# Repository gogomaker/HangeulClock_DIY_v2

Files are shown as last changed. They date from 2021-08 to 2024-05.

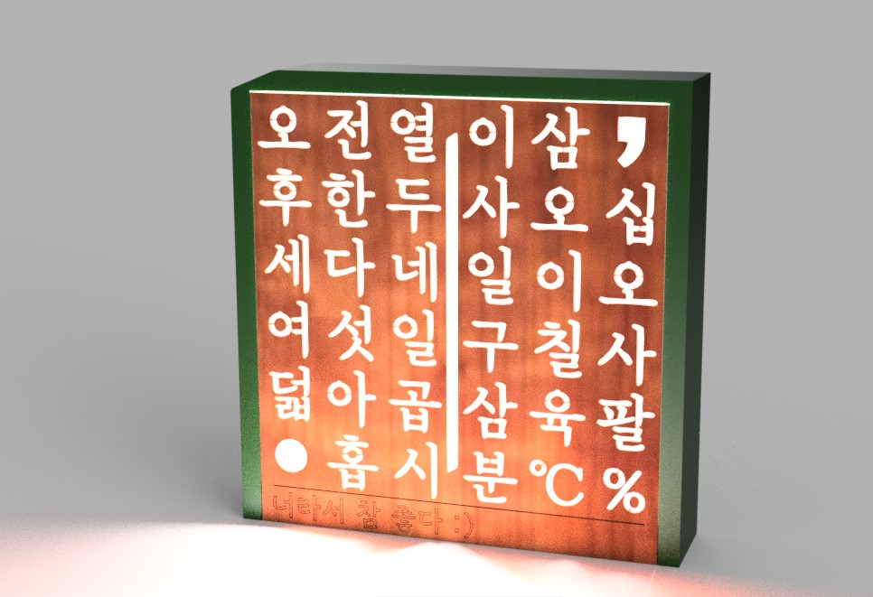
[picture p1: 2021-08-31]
.other_data/렌더링_1.jpg

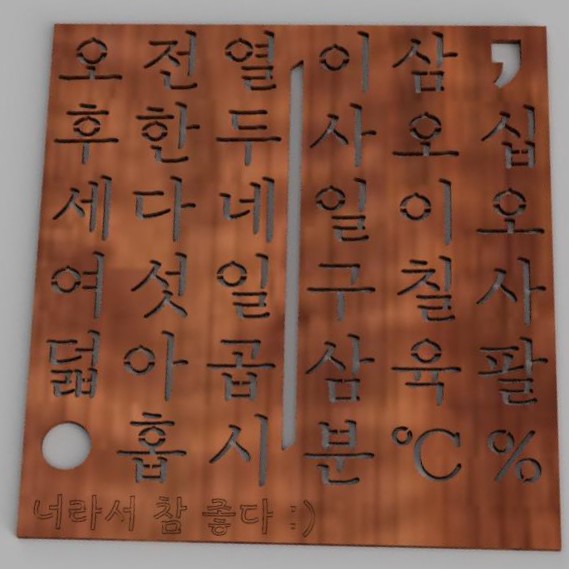
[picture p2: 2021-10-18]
.other_data/한글시계판 렌더링.jpg

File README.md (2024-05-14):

# HangeulClock_DIY_v2
한글시계 v2 - v1을 바탕으로 완전히 새롭게 만드는 v2

## 제작동기: 한글시계 v1을 만들면서 든 한 가지 생각...

'이야 남의 것 배껴서 똑같이 만들었는데 내가 응용해서 만든 것도 하나 있어야지 않겠나...' \
그래서 만들게 된 한글시계 v2 이다. \
-사실 말만 v2이지 상당히 다른 구조를 가지고 있다.

## 이번 프로그래밍에 중요한 사항

특별히 중요한 것은 모든 것을 "함수화"한다는 것이다.

모든 함수는 각자의 기능에 충실하게 작성되어야 하며, 함수 용도 외의 타용도의 코드가 작성되면 안 된다. 반드시 해당 기능만 있어야 한다.

## V2 개선사항(고쳐야 할 점)

PCB에서 flicker 제어선으로 빠지는 곳에 있는 10k옴저항 제거

PCB에 RESET button 추가 및 케이스에 이를 적용

케이스 무게 어떻게든 줄이기(디자인 조정), 전선 꼽히는 부분 조절

외부밝기측정부 재설계(부품이 안 맞으니 조립이 안 됨)

시계의 가장자리 부분으로 빛이 샌다. 이것을 해결할 방법을 찾아야 함.

회로설계에서 버튼핀 재배열 좀 하자(어째서 모드버튼만 2번인가)

아두이노 내부의 전체 순서를 결정하는 time 변수는 이름을 internal_millis 내지는 '내부의 시간기준'이란 뜻을 가질 수 있는 이름으로 변경하기

한글시계 온습도 표시 시에 온도 및 습도(단위)는 네오픽셀 색깔을 다르게 하자.\
색깔이 같으면 숫자 읽을 때 햇갈릴 수도 있을 듯

스위치 디바운싱을 소프트웨어로 처리하지말고 하드웨어로 처리하자. 그럼 얼마나 편하겠니...

## 구현해야하는 기능
버튼을 일정 시간(1200ms)이상 누르고 있으면, 자동으로 길게 누른 것으로 인식해서 작동하는 것. 이 기능이 제대로 작동하지 않음.

## 제작시 참고사항

v1과 달라진 점:

1. 중앙 flicker 추가 - 3번 핀 아날로그 출력 연결

2. 온습도 센서 추가    - 8번 핀 디지털 연결

3. 조도센서 추가     - A1 핀 아날로그 입력 연결

4. 부저 추가 (알람)  - 7번 핀 디지털 연결

5. 각종 버튼 추가    - 각 기능 구현

## 기능별 설명

네오픽셀은 기존의 무지개 색상 및 WarmLED를 추가하였고 이걸 따로 조합해야함

이번 버전에서는 Warm White 기본, 쿨화이트, 무지개 순으로 색깔 진행

~~랜덤의 경우 더 많은(30색)의 색상에서 랜덤으로 추출 가능하도록 설정~~

---

플리커(중앙에 깜빡이는 놈)는 1초마다 켜젔다 꺼졌다를 반복함

타임라인 상으로 보자면

0.0 --- 1.0 --- 2.0 --- 3.0 --- 4.0 s\
O N --- OFF --- O N --- OFF --- O N ... \
이런 형태를 취함

그리고, 이렇게 ON OFF 가 바뀌는 과졍에서 
조금 부드럽게, 그러나 탄력있게 바뀌도록 설계 \
마치 모션 그래픽처럼 \
+탄력있는 건 매우 어려움 \
+플리커는 모든 기능에서 깜박인다, 2초 간격

---

조도센서는\
밝기 조정 모드에서 밝기를 외부 조도에 맞게 
제어하는 모드를 넣음으로써 구현

--------------------------------

온습도 센서는

시계 전면의 버튼을 통하여 시계 - 온습도 표시 모드 변경함\
이 떄, 온도 또는 습도를 2자리 7세그먼트로 보여줌\
ex) *은 LED 점등, .은 LED 소등

    * * *  * * *

    . . *  * . *

    * * *  . . *

    * . .  . . *

    * * *  . . *

    x . .  . . -

    (-는 온습도  LED입니다)

센서는 2초에 1회 업데이트 되며 
평상시에는 업데이트 하지 않다가 
온습도 모드 진입시에 온습도 데이터를 업데이트 하여 표시

--------------------------------

알람 기능은

알람 설정 버튼을 길게 누름으로서 알람 설정 모드로 진입 가능\
알람은 시간 설정하는 방법과 동일하게 설정이 가능하며

알람 설정 버튼을 짧게 누르면 2~5초 동안 알람이 켜져있는지 꺼져있는지가

화면에 O 또는 X 로 나타나게 됨

기능 구현은

가능하다면 DS3231의 내부 알람 기능을 활용하면 좋겠지만

안 된다면 아두이노에서 코드로 작성하는 것으로 함.

--------------------------------

버튼별 기능은

- 시계 전면의 모드 전환 버튼: 모드 전환 역할

   이 버튼은 눌렀다가 땔 때 시간에 관계없이 모드만 바꿔줌.

- 시계 측면 위의 LED 버튼: LED관련 제어 역할

   이 버튼은 짧게 누르면 밝기 변화 길게 누르면 색상이 변화함.

   색상 변화는 네오픽셀 항목 참조.

- 시계 측면 둘째 시간 버튼: 시간을 수정하는 역할

   이 버튼은 처음에 짧게 누르면 반응 없음 길게 누르면 시간 수정 모드로 젼환함.

   시간 수정모드에 진입하게 되면 모든 시간을 표시하는 LED가 깜박임

   이후, 시간 버튼을 짧게 누르면 시단위 1씩 추가 알람 버튼을 짧게 누르면 분단위 1씩 추가된다.

   시간 버튼을 다시 길게 누르면 시간 수정 모드는 종료됨.

- 시계 측면 셋째 알람 버튼: 알람을 설정하는 버튼

   이 버튼은 처음에 짧게 누르면 알람이 활셩화 되어 있는지 아닌지 표시함 \
   시간 버튼과 알람 버튼을 같이 누르게 된다면(오차 20ms이내) 알람을 활성화&비활성화함 \
   이 때 가능하다면 \
    알람이 활성화 될 때는 X가 사라지며 O가 나타나고 \
    알람이 비활성화 될 때는 O가 사라지며 X가 나타나도록 한다.

   처음에 길게 누르면 알람 설정을 하게 된다. \
   이후, 시간 버튼을 짧게 누르면 알람 시단위 1씩 추가 \
   알람 버튼을 짧게 누르면 알람 분단위 1씩 추가된다.\
   알람 버튼을 길게 누른다면 O가 나타나고, 알람은 활성화 된 상태로 알람 설정 모드는 종료됨.

   + 시간 변경 시에는 쉼표가 파란색으로, 알람 변경시에는 쉼표가 녹색으로 점등된다.

## 제작일기
사실 깃헙 readme를 작성하면서 뭘 적아야 될지 모르겠어서 그냥 일기나 적으려 한다.

2021-03 어느 날: 한글시계 v2에 대한 소망과 희망을 가지고 대략적인 디자인 및 기능들을 일주일에 걸쳐 구상한다.

2021-05-29: 한글시계 v2 디자인 착수. 앞판 디자인 완료. 

2021-05-30: 한글시계 v2 의 기본적인 디자인 완료. 

2021-06-07: 깃헙 레포지토리 생성.

2021-06-23: 오랜만에 이 프로젝트를 건드렸다.
지난 2주간 무드등 한글시계 작업한다고 어찌나 바빴던지...
여튼 오늘은, 프로젝트의 실제 파일들을 복사하고, 깃 레포지지토리와 연동시켰다.

2021-08-31: 진짜 오랜만에 일지를 쓴다.
그동안 무드등 한글시계 PCB 작업하느랴 이것저것 만지느랴 바빴다.
그러나 지난 2주 동안, 디자인 및 PCB작업을 모두 완료하였으며, 다음주 중으로 모든 부품과
PCB가 온다.
이제 납땜을 하고 프로그램을 올리면 끝이 난다.
추석 전으로 마무리 하려는데 가능할련지...

2021-09-02: 남는 건 기록밖에 없다...
오늘은 DHT센서 라이브러리를 추가하고, 사용하는 핀을 상수로 지정하였으며, 
모든 기능에 대해 상당히 구체적으로 기술하였다.
위에 보는 바와 같이 말이다.
그리고, 변수명은 아직 못 바꿨다. 그리고 새로운 변수도 추가를 못했다.
내일 흐름을 짜면서 변수들도 필요한 것들 추가하고, 코드를 재정비 해야겠다.

2021-09-08: 간만에 리드미 적는다. 
이번주 토요일에 온라인 발표를 하기에 정신없이 발표 준비중이다.
함꼐 더불어, 코드와 모든 것을 열심히 하고 있다. 
어제 알리에서 SK6812LED를 잘못 보내준 것을 알고...ㅜ.ㅜ 
직구는 언제나 조심해야 하는 것 같다.
오늘은 정신없이 버튼 함수를 뜯어고치는 중이다.

2021-09-09: 이번주는 한글시계로 달리는 주간인가보다. 
오늘은 코드 수정을 정말 열심히 했다. 
v1의 유산을 모두 청산하고, 본격적인 v2 코드의 모습을 잡아가기 시작했다. 
기존에, 나의 기억력으로 숫자로만 지정한 것들도 모두 상수로 전환하고, 
변수 이름의 통일성 없는 것도 모두 새롭게 이름을 바꾸었으며, 
배열을 사용할 수 있는 것은 배열을 사용하였고, 
변수들을 카테고리 별로 정리, 각각 주석을 적었다. 
또한, h파일의 어수선함도 정리하였다.

2021-09-11: 오늘은 영메이커 놀이데이에서 한글시계 관련 발표를 하였고, 
한글시계 PCB의 문제점 중에서 스케치를 바꿔야 하는 작업 빛 푼프린트 수정 작업을 완료하였다..
내일은 PCB아트웤만 끝내면 된ㄷr...

2021-09-15: 그저께부터 3일간 PCB의 문제를 해결하고, 각 부품에 대한 호환성 및 기타 
모든 것을 비교한 결과, 현재로서 완벽하다고 판단되는 PCB를 주문하였다.
이제, 코드에 전력을 기한 다음, 다른 모양의 시계도... ㅎ.ㅎ

2021-10-18: 거의 한 달이 지났다... 
우선, LED는 불량이 와서 문제가 생겼고, 국내에서 구해야 할 것 같다. 
코드의 경우는 지난번의 기억을 더듬어서 마저 작업하던 cpp파일을 이어 수정하였다.
현재, updateHour까지 편집을 완료하였다. 다음부터는 updateMin 함수 편집을 시작하면 된다.

2021-11-15: 또 한 달이 지나서야 리드미를 쓴다. 
그제, 어제, 오늘동안 updateHour, updateMin 수정완료하였다(if->case). 
또한, 변수들을 전부 확인 완료하였다. (더 이상 수정할 변수 없음)
이젠 버튼 함수와 새로운 기능들을 추가해야지...

2021-11-22: 무슨 한글시계 개발을 일주일 간격으로 하는 것 같다...ㅋㅋ 
도대체 이게 무슨 일인지.... 

2022-01-06: 새로운 한 해가 밝았다. 
지난 6일동안 열심히 납땜하고 삽질한 결과, 하드웨어는 성공적으로 완성하였다. 
어제오늘로 나눠 테스트 한 각 부품들의 상태도 최고. 
이제 이 위에서 돌아갈 코드만 짜면 끝난다...

2022-01-09: 벌써 일지 작성한지 3일이 지났네... 
깃헙을 보면 알겠지만, 지난 3일동안 절대 논 것이 아니라 너무 빡세게 코딩 작업을 해서 일지를 안 쓴거다(까먹은 거 안 비밀). 
여튼간에, 오늘까지의 작업을 대략 정리하자면

1. 보기 힘들었던 변수 상태들 싹다 정리
2. 이해 안 갔던 변수 및 함수들 전부 주석 달음
3. 안 쓰는 과거의 코드 다 지움
4. if문들 대거 정리
5. 오늘 새벽 작업 포함 알람 기능까지 작성 완료.

오늘 저녁까지(작성당시 새벽) 프로그래밍 작업 완료하면, 코드 종이에 그려 보면서 오류 있는지 없는지 체크, 논리상 오류나는 부분 없으면 바로 한글시계에 업로딩 해서 실제 테스트를 진행해 본다.

2024-04-27: 이 프로젝트를 마무리한지도 어느덧 1년이 지났다. 대학교 오고 나서 시간이 나기도 하고, 다시 제대로 살려보고 싶어서 코드에 손 대보게 되었다. 진짜로 살려보자. 이제는 나도 능력이 성장했으니...

2024-05-03: 다른 프로젝트로 바쁜 와중에, 이것까지 하려니 정신이 없다. 그래도 내가 하고 싶어서 하는 거다 보니 열정이 난다. 오늘은 코드를 정리하고, 나도 모르게 꼬여 있었던 깃 브랜치를 정리하였다. 

2024-05-04: 오늘도 제법 많은 코드를 정리했다. 브랜치를 하나 별도로 만들어서, 코드를 전체적으로 수정 중에 있다. 

2024-05-06: 새벽에 코드작성하면서 일지를 적어본다. 이제 거의 모든 코드를 다 작성했다. 이제는 실전만 남았다. 과연 수정한 코드가 제대로 작동할지 정말로 궁금하다.

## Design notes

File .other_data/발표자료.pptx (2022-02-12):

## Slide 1

## 한글시계 V2

Maker. Son

## -모닝을 외치는 사람

뻘짓과 삽질 없이 무엇을 이루겠는가
무언가를 만들기 위해서는
시간과 자원을 갈아 넣어야 한다

## 발표할 내용 01

한글시계란

02

한글시계v2

03

제작과정

04

향후계획

## 한글시계란

## 한글시계란

- 한글로 시간을 표현하는 시계
- 숫자가 아닌 다른 방법으로 나타내는 시간
- 이호민 작가님이 처음 만드시고, 이후 수많은 리메이킹이 진행되고 있음.

## 새로움 시계 강력함 빛

한글시계 v2

기존의 v1및 타작품과는 전혀 다른 생김새와 기능

시간을 보는 방법에 대한 새로운 정의

강력한 성능
다양한 기능

LED로 나타내는
빛의 아름다움

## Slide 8

v1

한글시계 v2

v2

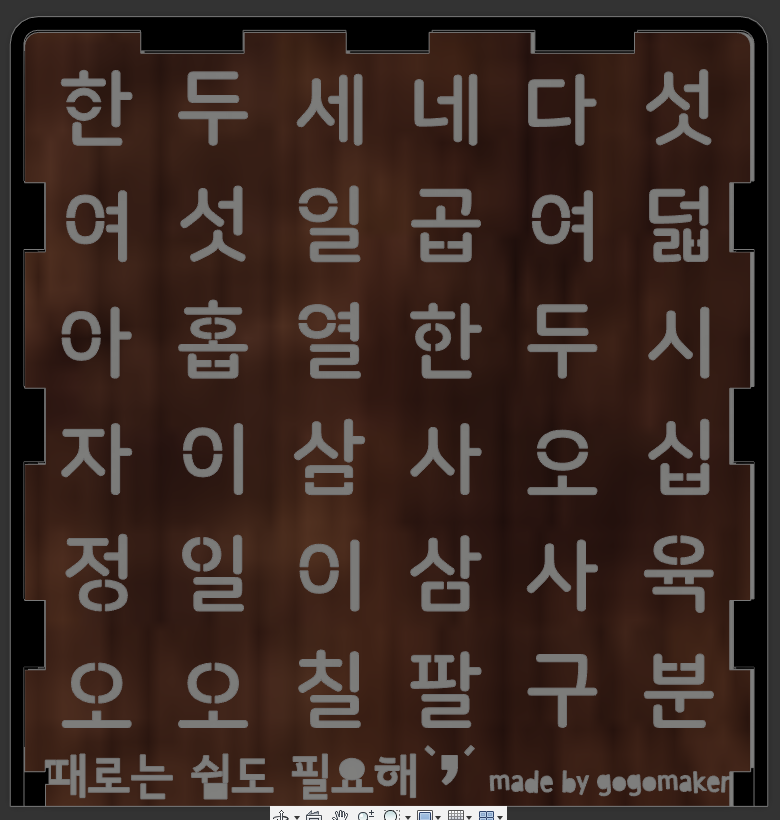
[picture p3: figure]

가로 110mm
세로 115mm
두께 16.5mm

회로 외부 노출
단순 시간 표시
작은 크기
(탁상형)

모든 부품 내장
다양한 기능
큰 크기
(어디든 좋음)

가로 173mm
세로 176mm
두께 37.3mm

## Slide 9

한글시계 v2

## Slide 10

한글시계 v2

Powered by Arduino Nano
Atmega328(16MHz, 32KB)
DS3231 (1년 ± 2초)
DHT22 (고정밀)
NeoPixel LEDs (강력함)

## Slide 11

한글시계 v2

Powered by Arduino Nano
시간 표시 기능
온습도 표시 기능
알람 기능
주/야간 밝기 자동조절

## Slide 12

한글시계 v2

1680만 컬러가 느끼게 해 주는
최고의 RGB경험을
느껴보세요

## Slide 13

제작과정

아이디어 짜기

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
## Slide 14

향후계획

‘v3’

아름다움

## 감사합니다

추가적인 질문사항 및 문의사항은
영메이커 네트워크
or
daseulgi100@gmaIl.com
카카오톡 오픈채팅 검색: 시계광05
Instagram: son.hayong
facebook.com/son0dragon

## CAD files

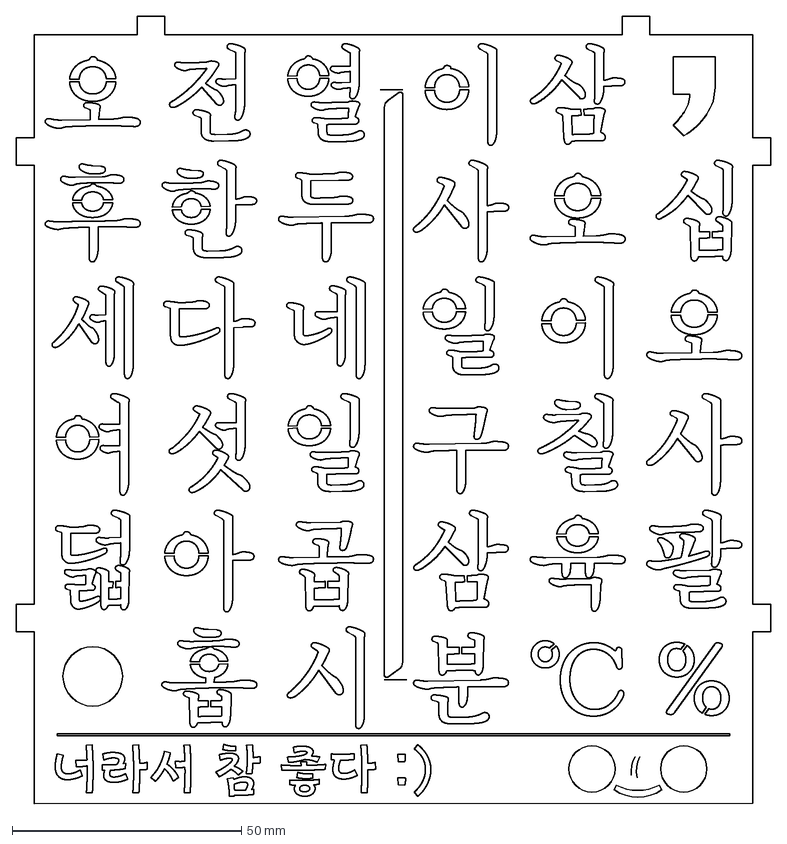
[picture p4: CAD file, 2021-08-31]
design/External_design/letter_panel.dxf
164.5 x 171.5 mm

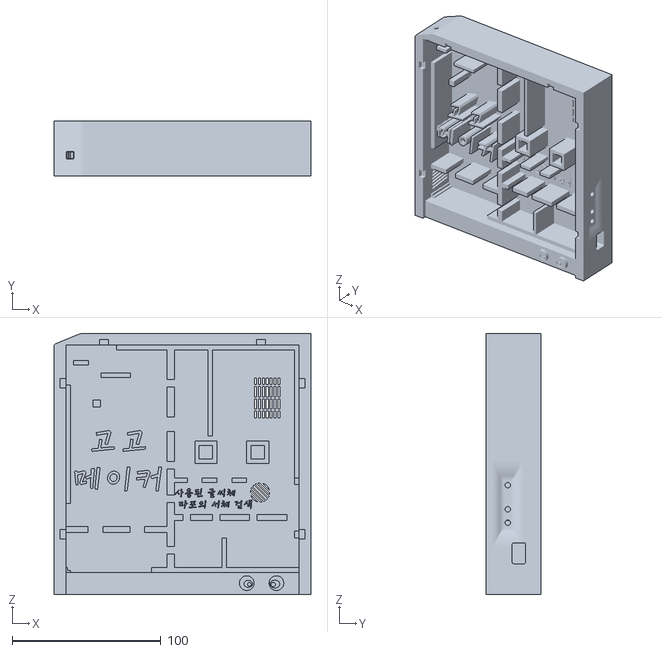
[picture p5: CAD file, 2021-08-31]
design/External_design/case.stl
173.0 x 37.3 x 176.0

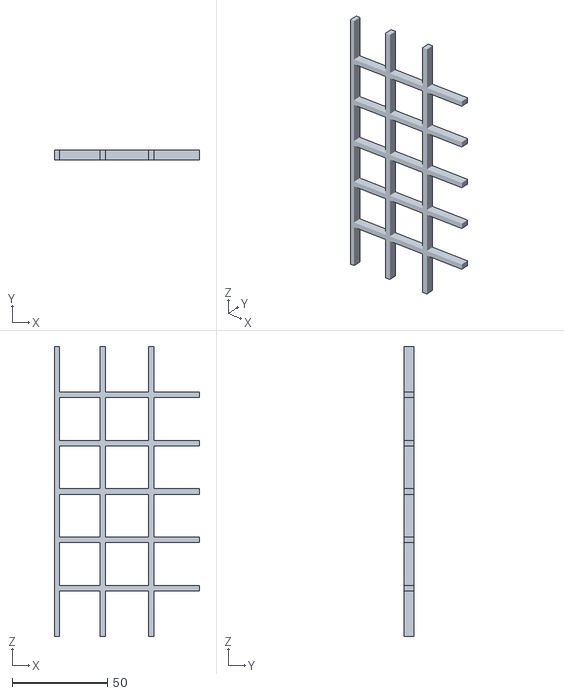
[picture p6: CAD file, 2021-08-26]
design/External_design/partition_R.stl
76.2 x 5.00 x 152.5

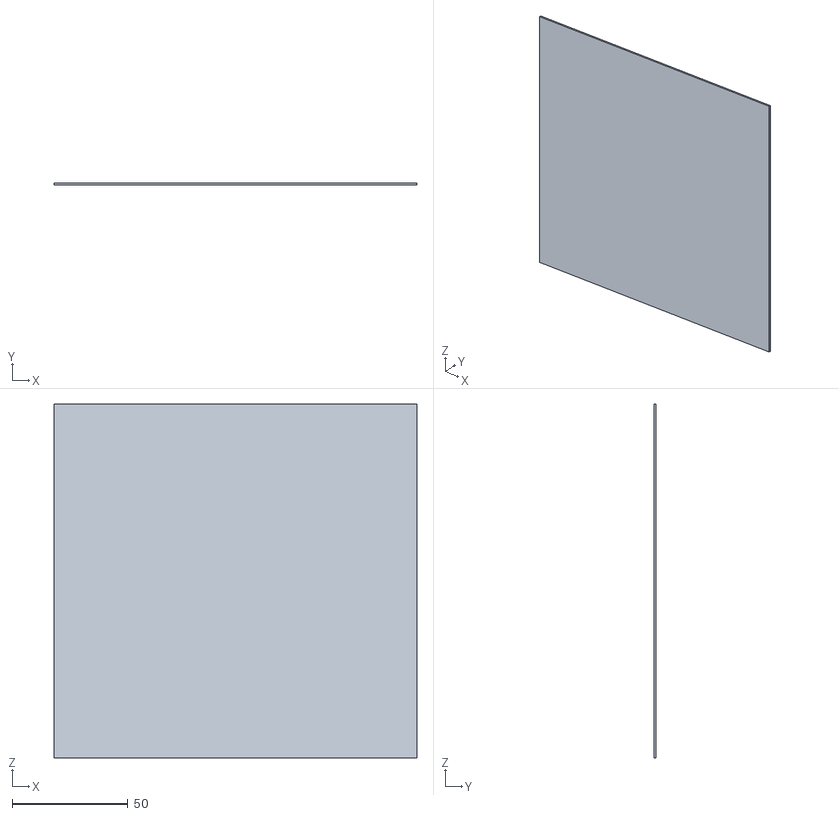
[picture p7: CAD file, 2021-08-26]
design/External_design/diffuser.stl
156.5 x 1.00 x 152.5

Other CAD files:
design/External_design/partition_L.stl

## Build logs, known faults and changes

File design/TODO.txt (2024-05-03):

TO-DO

 - PCB받침대(?) 생성
 - 부저 & 온습도 센서 구멍 뚫기
 - 조도센서 부분 구멍 뚫기
 - 측면 버튼 부분 구멍 뚫기
 - 아두이노 단자 부분 구멍 뚫기
 - 케이스 측면 구멍 뚫기(작게, 환기위함)
정면 버튼 버튼캡 제작하기
 - 부가적 - 
초 표시기능 생각해 보기 바람(??!!)

2차 TO-DO

레터 패널과 본체가 결합되게 하라!

1. 하단의 응원문구 남는 부분에 사각형 돌출
2. 각 테두리마다 홈을 팜
3. 다 이루었뜨아

근데 다른 고정 방법은 없으려나...

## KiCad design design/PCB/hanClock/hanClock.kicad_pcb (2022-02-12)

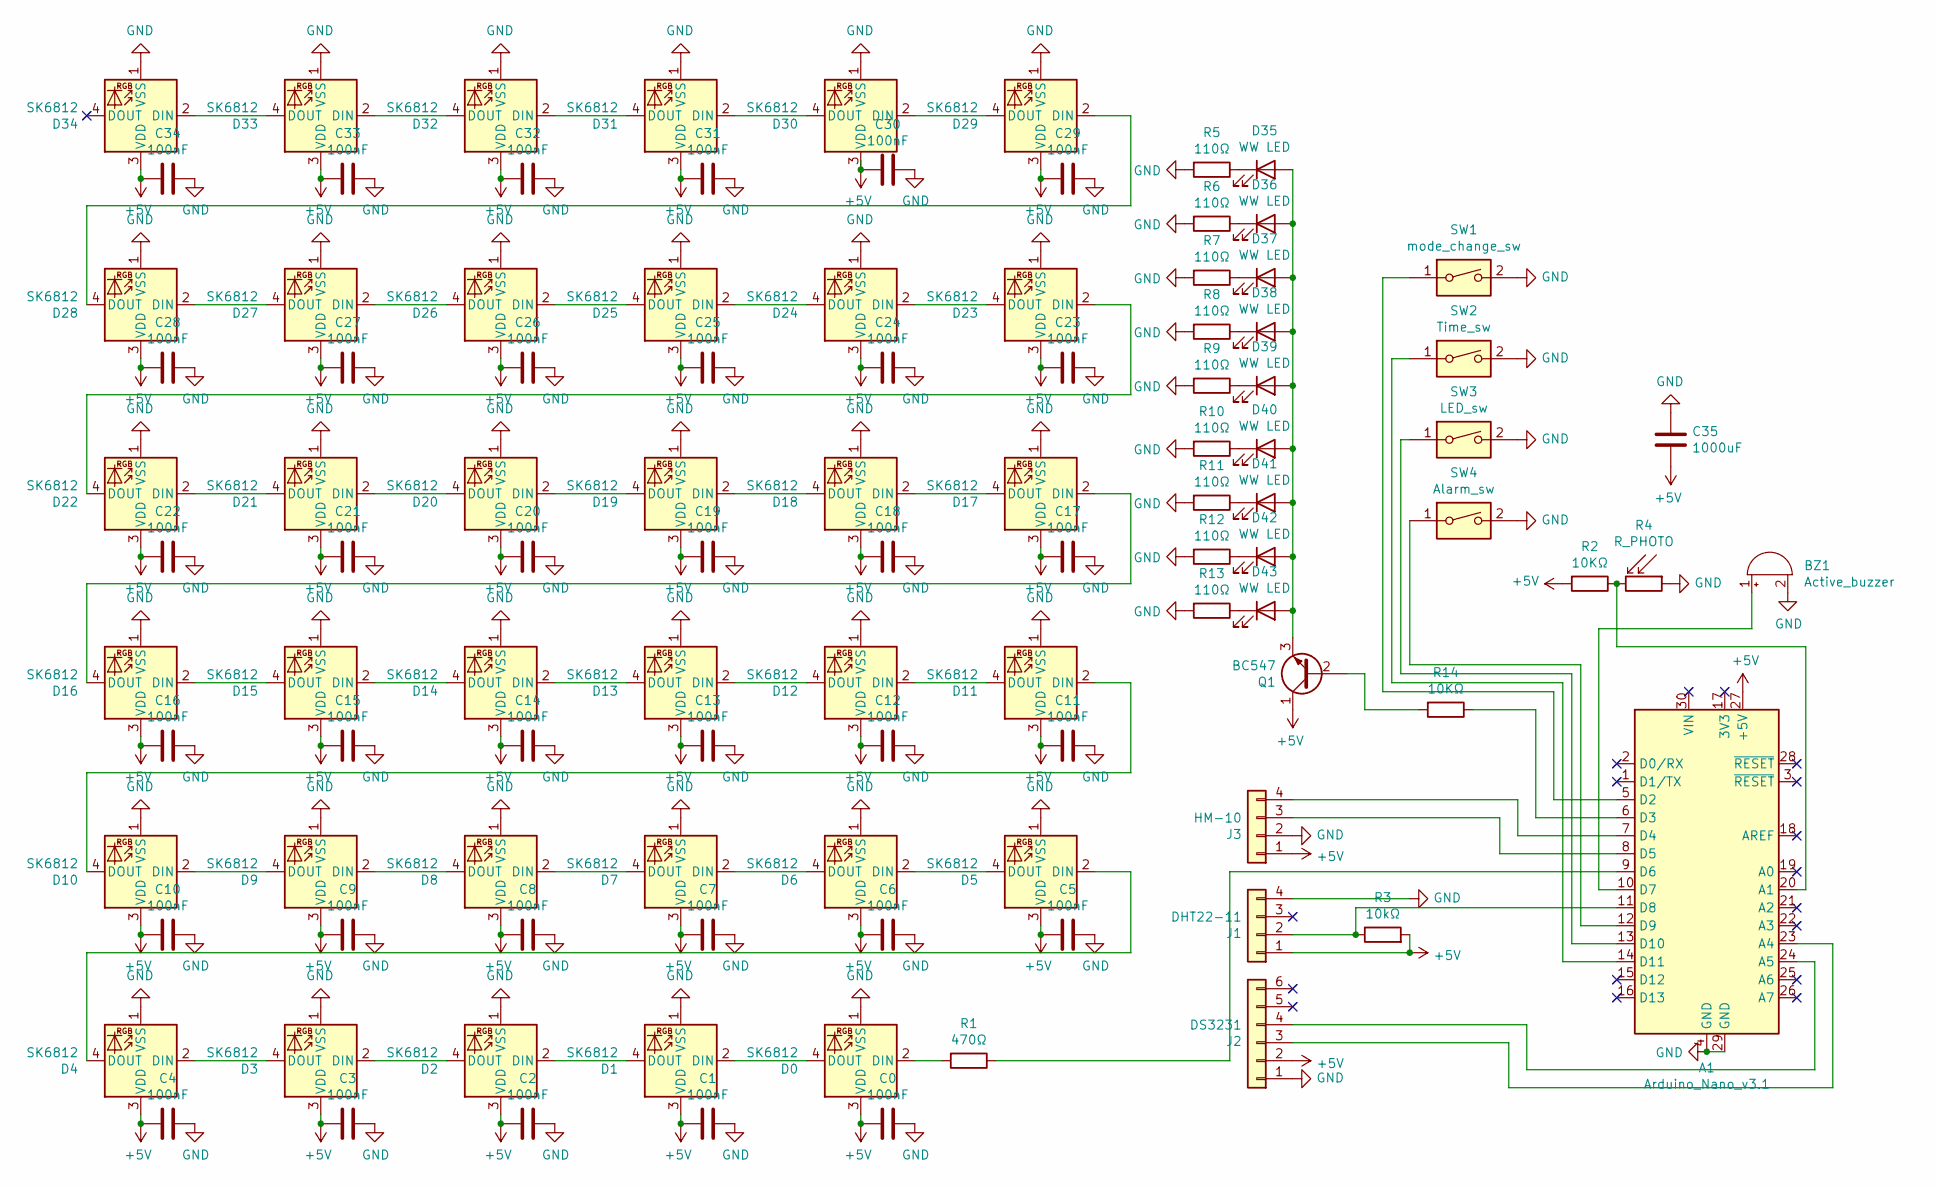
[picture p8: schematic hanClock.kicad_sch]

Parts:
A1: Arduino_Nano_v3.1; Arduino_Nano
BZ1: Active_buzzer; buzzer
C0, C1, C2, C3, C4, C5, C6, C7, C8, C9, C10, C11, C12, C13, C14, C15, C16, C17, C18, C19, C20, C21, C22, C23, C24, C25, C26, C27, C28, C29, C30, C31, C32, C33, C34: 100nF; C_1206_3216Metric_Pad1.33x1.80mm_HandSolder
C35: 1000uF; C_K14
D0, D1, D2, D3, D4, D5, D6, D7, D8, D9, D10, D11, D12, D13, D14, D15, D16, D17, D18, D19, D20, D21, D22, D23, D24, D25, D26, D27, D28, D29, D30, D31, D32, D33, D34: SK6812; LED_SK6812_PLCC4_5.0x5.0mm_P3.2mm
D35, D36, D37, D38, D39, D40, D41, D42, D43: WW LED; LED_1206_3216Metric_Pad1.42x1.75mm_HandSolder
J1: DHT22-11; PinSocket_1x04_P2.54mm_Vertical
J2: DS3231; PinSocket_1x06_P2.54mm_Vertical
J3: HM-10; PinSocket_1x04_P2.54mm_Vertical
Q1: BC547
R1: 470Ω; R_Axial_DIN0207_L6.3mm_D2.5mm_P10.16mm_Horizontal
R2, R14: 10KΩ; R_Axial_DIN0207_L6.3mm_D2.5mm_P10.16mm_Horizontal
R3: 10kΩ; R_Axial_DIN0207_L6.3mm_D2.5mm_P10.16mm_Horizontal
R4: R_PHOTO; R_Axial_DIN0204_L3.6mm_D1.6mm_P2.54mm_Vertical
R5, R6, R7, R8, R9, R10, R11, R12, R13: 110Ω; R_1206_3216Metric_Pad1.30x1.75mm_HandSolder
SW1: mode_change_sw; SMDbutton
SW2: Time_sw; KLT_SW
SW3: LED_sw; KLT_SW
SW4: Alarm_sw; KLT_SW

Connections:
+5V: A1.27 (+5V), C0.2, C1.2, C2.2, C3.2, C4.2, C5.2, C6.2, C7.2, C8.2, C9.2, C10.2, C11.2, C12.2, C13.2, C14.2, C15.2, C16.2, C17.2, C18.2, C19.2, C20.2, C21.2, C22.2, C23.2, C24.2, C25.2, C26.2, C27.2, C28.2, C29.2, C30.2, C31.2, C32.2, C33.2, C34.2, C35.2, D0.3 (VDD), D1.3 (VDD), D2.3 (VDD), D3.3 (VDD), D4.3 (VDD), D5.3 (VDD), D6.3 (VDD), D7.3 (VDD), D8.3 (VDD), D9.3 (VDD), D10.3 (VDD), D11.3 (VDD), D12.3 (VDD), D13.3 (VDD), D14.3 (VDD), D15.3 (VDD), D16.3 (VDD), D17.3 (VDD), D18.3 (VDD), D19.3 (VDD), D20.3 (VDD), D21.3 (VDD), D22.3 (VDD), D23.3 (VDD), D24.3 (VDD), D25.3 (VDD), D26.3 (VDD), D27.3 (VDD), D28.3 (VDD), D29.3 (VDD), D30.3 (VDD), D31.3 (VDD), D32.3 (VDD), D33.3 (VDD), D34.3 (VDD), J1.1, J2.2, J3.1, Q1.1 (C), R2.2, R3.2
GND: A1.4 (GND), A1.29 (GND), BZ1.2 (+), C0.1, C1.1, C2.1, C3.1, C4.1, C5.1, C6.1, C7.1, C8.1, C9.1, C10.1, C11.1, C12.1, C13.1, C14.1, C15.1, C16.1, C17.1, C18.1, C19.1, C20.1, C21.1, C22.1, C23.1, C24.1, C25.1, C26.1, C27.1, C28.1, C29.1, C30.1, C31.1, C32.1, C33.1, C34.1, C35.1, D0.1 (VSS), D1.1 (VSS), D2.1 (VSS), D3.1 (VSS), D4.1 (VSS), D5.1 (VSS), D6.1 (VSS), D7.1 (VSS), D8.1 (VSS), D9.1 (VSS), D10.1 (VSS), D11.1 (VSS), D12.1 (VSS), D13.1 (VSS), D14.1 (VSS), D15.1 (VSS), D16.1 (VSS), D17.1 (VSS), D18.1 (VSS), D19.1 (VSS), D20.1 (VSS), D21.1 (VSS), D22.1 (VSS), D23.1 (VSS), D24.1 (VSS), D25.1 (VSS), D26.1 (VSS), D27.1 (VSS), D28.1 (VSS), D29.1 (VSS), D30.1 (VSS), D31.1 (VSS), D32.1 (VSS), D33.1 (VSS), D34.1 (VSS), J1.4, J2.1, J3.2, R4.1, R5.2, R6.2, R7.2, R8.2, R9.2, R10.2, R11.2, R12.2, R13.2, SW1.2, SW2.2, SW3.2, SW4.2
unnamed: A1.5 (D2), SW1.1
unnamed: A1.6 (D3), R14.1
unnamed: A1.7 (D4), J3.4
unnamed: A1.8 (D5), J3.3
unnamed: A1.9 (D6), R1.1
unnamed: A1.10 (D7), BZ1.1 (-)
unnamed: A1.11 (D8), J1.2, R3.1
unnamed: A1.12 (D9), SW4.1
unnamed: A1.13 (D10), SW3.1
unnamed: A1.14 (D11), SW2.1
unnamed: A1.20 (A1), R2.1, R4.2
unnamed: A1.23 (A4), J2.3
unnamed: A1.24 (A5), J2.4
unnamed: D0.2 (DIN), R1.2
unnamed: D0.4 (DOUT), D1.2 (DIN)
unnamed: D1.4 (DOUT), D2.2 (DIN)
unnamed: D2.4 (DOUT), D3.2 (DIN)
unnamed: D3.4 (DOUT), D4.2 (DIN)
unnamed: D4.4 (DOUT), D5.2 (DIN)
unnamed: D5.4 (DOUT), D6.2 (DIN)
unnamed: D6.4 (DOUT), D7.2 (DIN)
unnamed: D7.4 (DOUT), D8.2 (DIN)
unnamed: D8.4 (DOUT), D9.2 (DIN)
unnamed: D9.4 (DOUT), D10.2 (DIN)
unnamed: D10.4 (DOUT), D11.2 (DIN)
unnamed: D11.4 (DOUT), D12.2 (DIN)
unnamed: D12.4 (DOUT), D13.2 (DIN)
unnamed: D13.4 (DOUT), D14.2 (DIN)
unnamed: D14.4 (DOUT), D15.2 (DIN)
unnamed: D15.4 (DOUT), D16.2 (DIN)
unnamed: D16.4 (DOUT), D17.2 (DIN)
unnamed: D17.4 (DOUT), D18.2 (DIN)
unnamed: D18.4 (DOUT), D19.2 (DIN)
unnamed: D19.4 (DOUT), D20.2 (DIN)
unnamed: D20.4 (DOUT), D21.2 (DIN)
unnamed: D21.4 (DOUT), D22.2 (DIN)
unnamed: D22.4 (DOUT), D23.2 (DIN)
unnamed: D23.4 (DOUT), D24.2 (DIN)
unnamed: D24.4 (DOUT), D25.2 (DIN)
unnamed: D25.4 (DOUT), D26.2 (DIN)
unnamed: D26.4 (DOUT), D27.2 (DIN)
unnamed: D27.4 (DOUT), D28.2 (DIN)
unnamed: D28.4 (DOUT), D29.2 (DIN)
unnamed: D29.4 (DOUT), D30.2 (DIN)
unnamed: D30.4 (DOUT), D31.2 (DIN)
unnamed: D31.4 (DOUT), D32.2 (DIN)
unnamed: D32.4 (DOUT), D33.2 (DIN)
unnamed: D33.4 (DOUT), D34.2 (DIN)
unnamed: D35.1 (K), R5.1
unnamed: D35.2 (A), D36.2 (A), D37.2 (A), D38.2 (A), D39.2 (A), D40.2 (A), D41.2 (A), D42.2 (A), D43.2 (A), Q1.3 (E)
unnamed: D36.1 (K), R6.1
unnamed: D37.1 (K), R7.1
unnamed: D38.1 (K), R8.1
unnamed: D39.1 (K), R9.1
unnamed: D40.1 (K), R10.1
unnamed: D41.1 (K), R11.1
unnamed: D42.1 (K), R12.1
unnamed: D43.1 (K), R13.1
unnamed: Q1.2 (B), R14.2

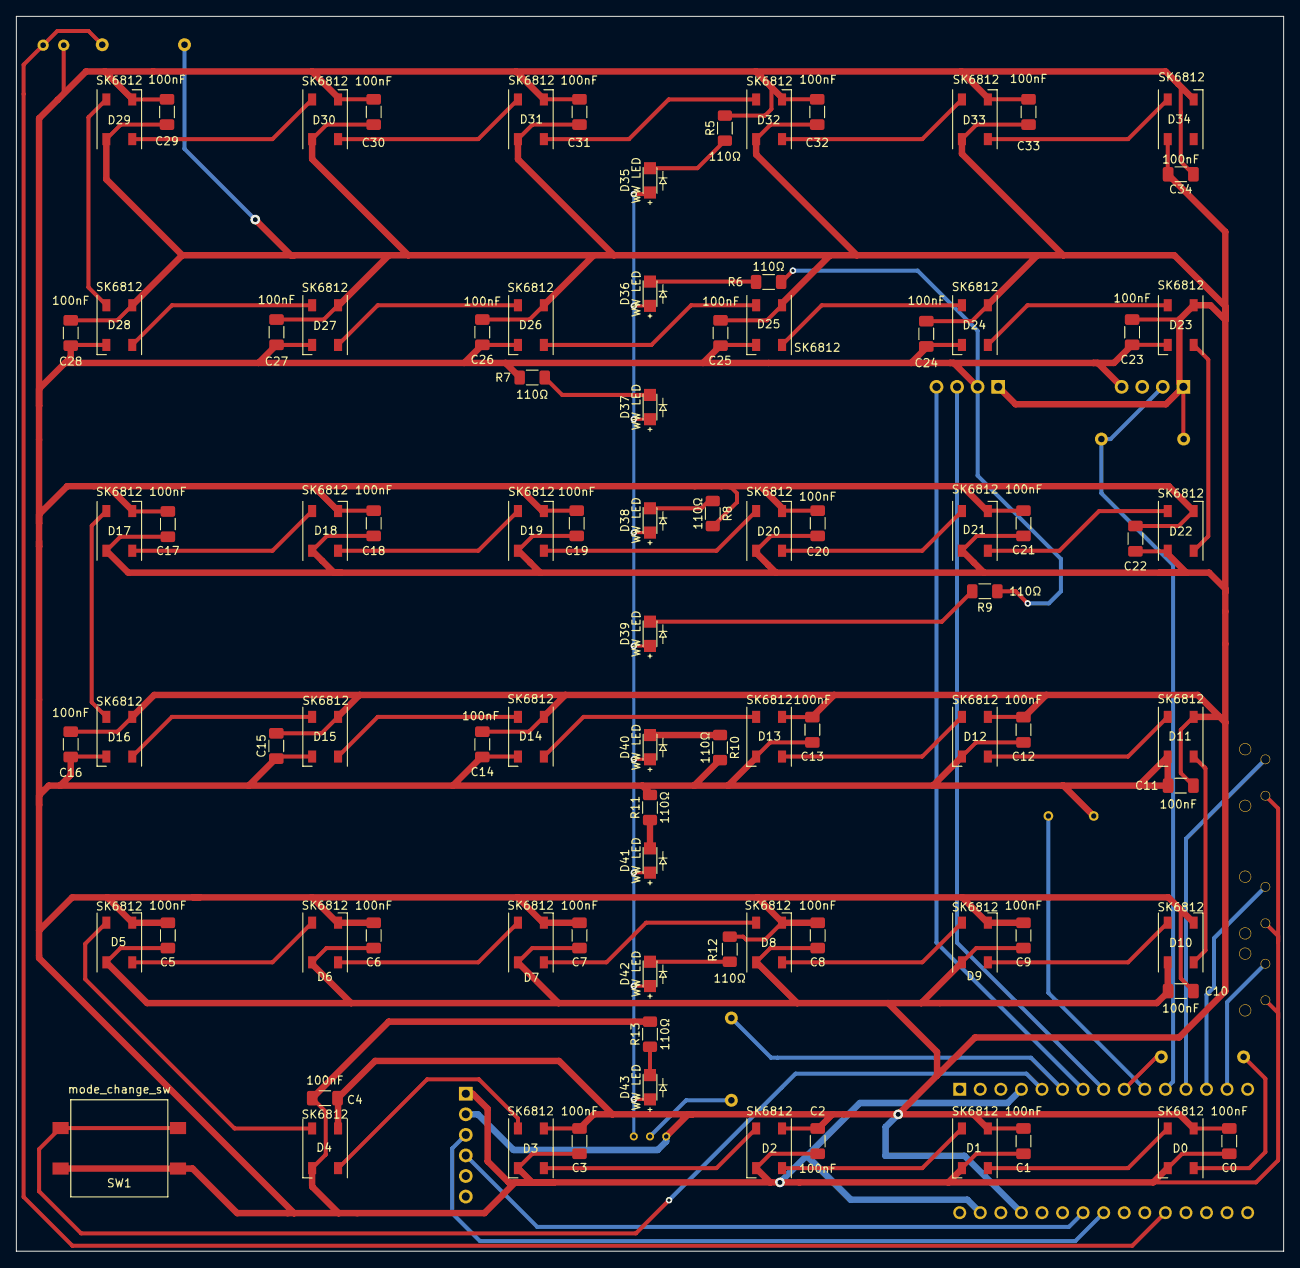
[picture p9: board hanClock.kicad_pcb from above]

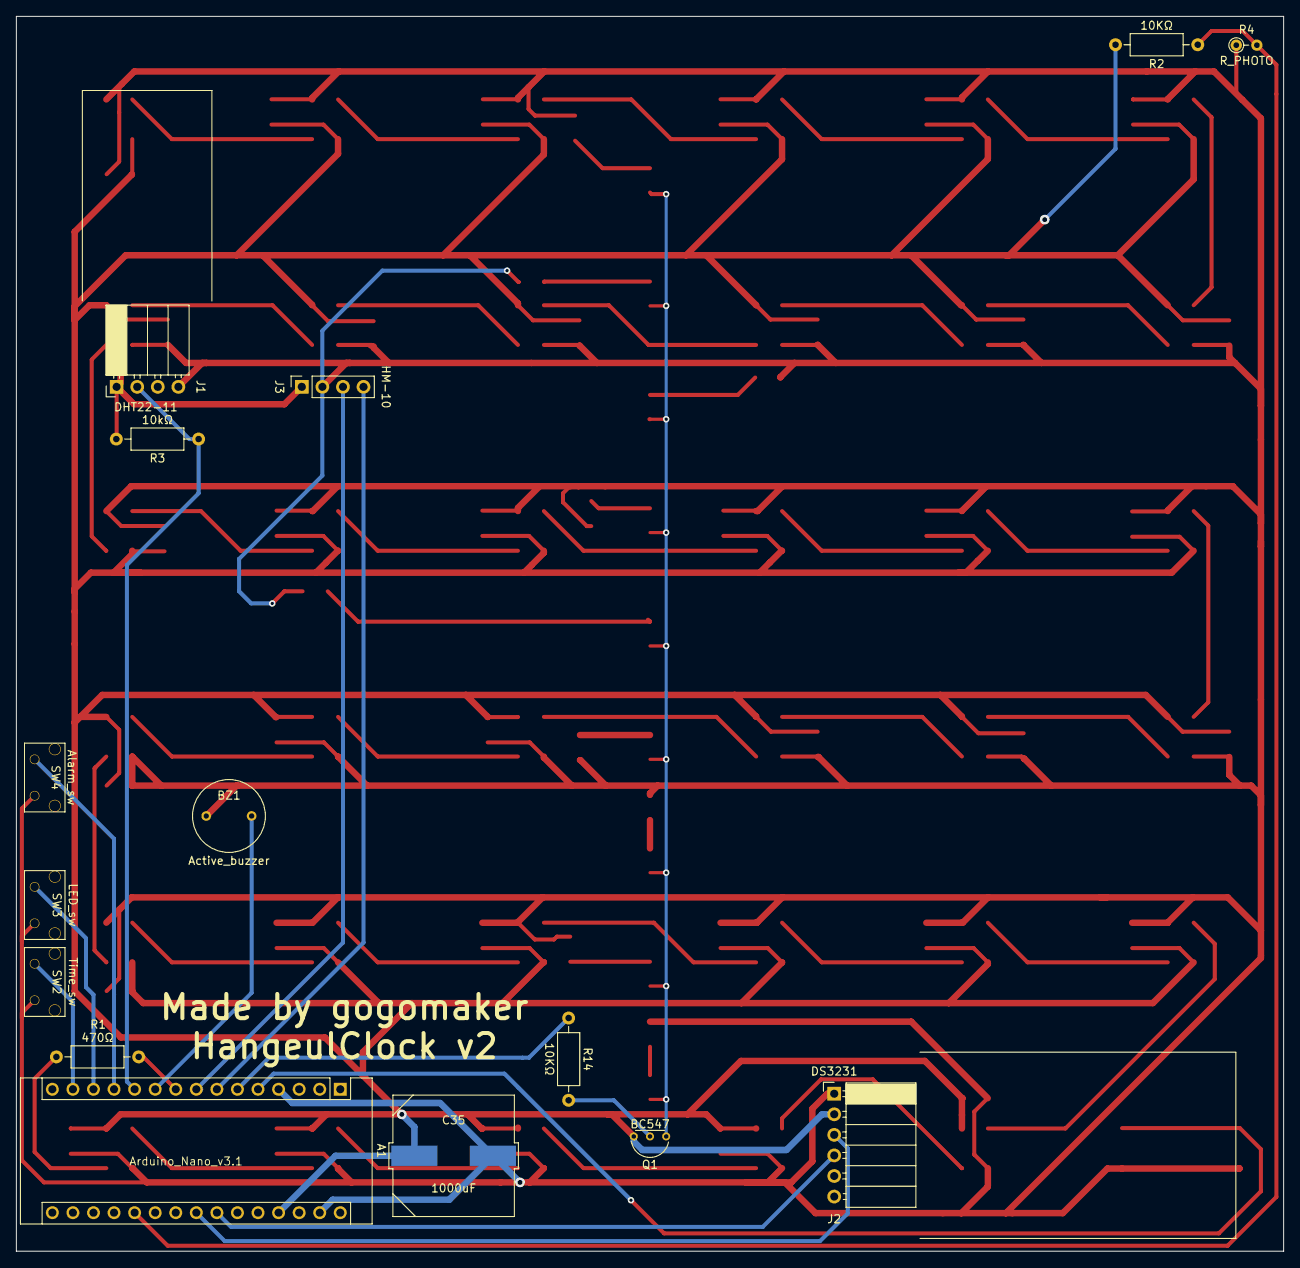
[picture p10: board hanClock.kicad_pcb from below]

Board: 2 copper layers, 156.5 x 152.5 mm, 104 parts (15 on the bottom side), 61 nets.

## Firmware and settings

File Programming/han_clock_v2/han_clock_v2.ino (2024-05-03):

/*
	Name:		han_clock.ino
	Created:	2021-06-23 오후 3:34:22	
	Author:	gogomaker
*/ /*
	이 프로그램은 한글시계 v2를 돌리는 프로그램이다.
	정말이지 v1과 프로그램은 비슷할 예정이지만
	온습도 측정 및 표시가 난관이 아닐까 싶다.
	항상 파이팅!
*/

/* 헤더파일 선언 */
#include "src\functions\functions.h"

/* 실제 변수 및 객체 선언 */
// 색상표 선언 - 수정해야 함(30가지 색)
const byte color[COLOR_CNT][4] {//R  , G  , B  , W  
  {0  , 0  , 0  , 255},		// 하얀색(warm white)
  {200, 200, 200, 0  },		// 하얀색(cool white)
  {255, 0  , 0  , 0  },		// 붉은색
  {255, 94 , 0  , 0  },		// 선홍색
  {255, 187, 0  , 0  },		// 주황색
  {255, 228, 0  , 0  },		// 노란색
  {171, 242, 0  , 0  },		// 연두색
  {29 , 219, 22 , 0  },		// 초록색
  {0  , 84 , 255, 0  },		// 하늘색
  {1  , 0  , 255, 0  },		// 파란색
  {95 , 0  , 255, 0  },		// 보라색
  {255, 0  , 221, 0  },		// 분홍색
  {255, 0  , 100, 0  }};	// 분홍과 빨강 사이 어딘가

// 형상에 대한 배열 선언
const byte shapeO[8] = {7, 8, 12, 21, 25, 26, 18, 15};		// O
const byte shapeX[8] = {27, 19, 13, 9, 24, 20, 14, 6};		// X
const byte numberTEN_segment[10][13] {
	{31, 30, 29, 28, 17, 16,  5,  6,  7, 14, 19, 26,  0},	// 0
	{30, 27, 18, 15,  6,  0,  0,  0,  0,  0,  0,  0,  0},	// 1
	{29, 30, 31, 26, 19, 18, 17, 16,  5,  6,  7,  0,  0},	// 2
	{29, 30, 31, 26, 19, 14,  7,  6,  5,  0,  0,  0,  0},	// 3
	{29, 28, 17, 18, 19, 31, 26, 14,  7,  0,  0,  0,  0},	// 4
	{31, 30, 29, 28, 17, 18, 19, 14,  7,  6,  5,  0,  0},	// 5
	{31, 30, 29, 28, 17, 16,  5,  6,  7, 14, 19, 18,  0}, // 6
	{17, 28, 29, 30, 31, 26, 19, 14,  7,  0,  0,  0,  0},	// 7
	{26, 31, 30, 29, 28, 17, 18, 19, 14,  7,  6,  5, 16},	// 8
	{18, 17, 28, 29, 30, 31, 26, 19, 14,  7,  6,  5,  0}};	// 9
const byte numberONE_segment[10][13] {
	{32, 33, 34, 23, 22, 11, 10,  9,  8, 13, 20, 25,  0},	// 0
	{33, 24, 21, 12,  9,  0,  0,  0,  0,  0,  0,  0,  0},	// 1
	{32, 33, 34, 23, 22, 21, 20, 13,  8,  9, 10,  0,  0},	// 2
	{32, 33, 34, 23, 22, 21, 20, 11, 10,  9,  8,  0,  0},	// 3
	{32, 25, 20, 21, 34, 23, 22, 11, 10,  0,  0,  0,  0},	// 4
	{34, 33, 32, 25, 20, 21, 22, 11, 10,  9,  8,  0,  0},	// 5
	{34, 33, 32, 25, 20, 13,  8,  9, 10, 11, 22, 21,  0},	// 6
	{20, 25, 32, 33, 34, 23, 22, 11, 10,  0,  0,  0,  0},	// 7
	{23, 34, 33, 32, 25, 20, 21, 22, 11, 10,  9,  8, 13},	// 8
	{21, 20, 25, 32, 33, 34, 23, 22, 11, 10,  9,  8,  0}};	// 9

// 객체 선언
Adafruit_NeoPixel strip(LED_CNT, NEOPIN, NEO_GRBW + NEO_KHZ800);

//네오픽셀 관련 변수
byte r, g, b, w = 255;	// 네오픽셀 LED
byte bright = 180; 		// 255가 최대, 0이 최소, 7단계 제어
byte ledmode = 0;		// 13개의 색 - 다채로운 30개 목표

//버튼 관련 변수
int swpin[4] = {MOD_SW, LED_SW, TIME_SW, ALARM_SW};	//단순히 핀 매핑해 놓은 것 뿐
bool sw_org_stat[4] = {HIGH, HIGH, HIGH, HIGH};  // 체터링을 거른 버튼의 상태를 표현하는 변수
bool l_sw_stat[4]   = {HIGH, HIGH , HIGH, HIGH}; // 마지막 버튼 상태
int sw_prcs_val[4]  = {0, 0, 0, 0};				// 버튼을 프로그램에서 처리할 때 사용하는 값
unsigned long l_deb_tme[4] = {0, 0, 0, 0};		// 디바운스 시간 체킹
unsigned long sw_w[4] = {0, 0, 0, 0};			// 시간 버튼이 언제 눌렸는가

// RTC모듈 관련 변수
byte tMSB, tLSB;  // RTC온도관련
float temp3231;

//시간 관련 변수
extern volatile unsigned long timer0_millis;	// millis 오버플로우 대비 초기화
unsigned long time = 0;			// 아두이노 내부 밀리초 값
byte sec, lastSec = 0;			// 매 초 실행되는 기능을 위해
byte hourPlus, minPlus = 0;		// 시간 변경 시 임시적으로 값을 저장
byte minRtc, hourRtc = 0; 		// RTC의 시간값
byte min, hour = 0;   			// 실제 시간값
bool isResetMillis = false;		// millis오버플로우 초기화 여부
long rSeed = 0;					// LED랜덤색상 설정 시드값
bool isTchange = false;			// 시간수정모드 여부

// 온습도 관련 변수
float temp, humi, f;	//온도, 습도, 화씨
unsigned long dhtshowTime = 0;
bool isEnableShowDht = false;
unsigned long l_tempshow = 0;
unsigned long tempshow = 0;

// 알람 관련 변수
byte almHour, almMin, almSec = 0;	// 시 분 초
bool isonAlarm = false;				// 알람기능이 켜져 있는가
bool isAchange = false;				// 알람수정모드 여부
unsigned long l_showAstat_Time = 0;	//알람 상태를 보여주기 시작한 시간 기록 변수

// 아날로그 밝기 제어 관련 변수
int ext_bri = map(analogRead(EXT_BRIGHT), 0, 1023, MAX_BRI, 0);	// 외부 밝기값
//플리커 관련 변수
byte flick_bri = 0;	// 플리커 밝기 변수
//전체 모드 제어
byte clock_mode = 0;//0은 시계, 1은 온도, 2는 습도

void setup() 
{
	#if defined(__AVR_ATtiny85__) && (F_CPU == 16000000)
		clock_prescale_set(clock_div_1);
	#endif
	// I2C 통신시작
	Wire.begin();
	// 시리얼 모니터
	Serial.begin(9600);
	Serial.println("Hangeul Clock v2 has turn ON");
	Serial.println("Clock start");
	// 네오픽셀 초기설정
	strip.begin();
	strip.setBrightness(bright);
	strip.show();
	
	// 온습도 센서 초기설정
	//dht.begin();
	
	// 버튼입력설정
	pinMode(MOD_SW, INPUT_PULLUP);
	pinMode(LED_SW, INPUT_PULLUP);
	pinMode(TIME_SW, INPUT_PULLUP);
	pinMode(ALARM_SW, INPUT_PULLUP);
	pinMode(BUZZER, OUTPUT);
	pinMode(FLICKER, OUTPUT);
	
	// 시계에 시간 출력
	time = millis();
	get3231Date();
	hour = (hourRtc + hourPlus) % 24;
	min = (minRtc + minPlus) % 60;
	displayTime(hour, min);
}

void loop() 
{
	/* 사전설정 */ 
	time = millis();
	get3231Date();
	if(dhtshowTime < time) {
		//float humi = dht.readHumidity();
		//float temp = dht.readTemperature();
		if (isnan(temp) || isnan(humi)) {
			// 값 읽기 실패시 시리얼 모니터 출력
			Serial.println("Failed to read from DHT");
		}
		dhtshowTime += 2000;
	}
	if (!sec && !minRtc && !hourRtc) {	//millis 초기화
		if(!timer0_millis) isResetMillis = true;
		if (isResetMillis == true) {
			//Serial.println("Timer reset");
			for(int i = 0; i < 4; i++) {
				l_deb_tme[i] = 0;
				sw_w[i] = 0;
			}
			sw_w[3] = 0;
			time = 0;
			timer0_millis = 0;
			isResetMillis = false;
		}
	}
	/* 시계구동코드 */
	// 스위치 기반 작동 코드(LED밝기 및 색상, 시간 알람 편집 등)
	for (int i = 0; i < 4; i++) { 
		sw_prcs_val[i] = sensingSW(i); 
		Serial.print(sw_prcs_val[i]);
		Serial.print(" / ");
		}
		Serial.println();
	if (sw_prcs_val[LED_SW] == SHORT) { changeLEDbright(); }
	if (clock_mode == M_CLOCK) {
		if(sw_prcs_val[LED_SW] == LONG) { changeLEDcolor(); }
		if(isTchange) {
			if(sw_prcs_val[TME_SW] == SHORT) { increasingHour(); }	//시단위 추가
			if(sw_prcs_val[ALM_SW] == SHORT) { increasingMin();  }	//분단위 추가
			if(sw_prcs_val[TME_SW] == LONG) { endTchange(); }	//시간편집모드 종료
		}
		else if(isAchange) {
			if(sw_prcs_val[TME_SW] == SHORT) { increasingAlmHour(); }	//시단위 추가
			if(sw_prcs_val[ALM_SW] == SHORT) { increasingAlmMin();  }	//분단위 추가
			if(sw_prcs_val[TME_SW] == LONG) { endAchange(); }	//알람편집모드 종료
		}
		else {
			if(sw_prcs_val[ALM_SW] == SHORT) { changeAlmStat(); }	//알람 활성화 및 비활성화
			if(sw_prcs_val[TME_SW] == LONG) { startTchange(); }	//시간편집모드 시작
			if(sw_prcs_val[TME_SW] == LONG) { startAchange(); }	//알람편집모드 시작
		}
	}
	// 알람구동코드
	if(isonAlarm) {	//알람 활성화라면
		alarmMotion();
	}
	// 플리커 구동코드
	digitalWrite(FLICKER, sec%2);	// 원리를 보자면 짝수에는 false, 꺼지고 홀수에는 true, 켜진다.

	// 모드기반 기능구동코드(시간표시, 온도표시, 습도표시)를 처리할 수 있게 하는 코드
	if(!isAchange) {
		if (sw_prcs_val[MOD_SW]) { clock_mode = clock_mode > 1 ? 0 : + 1; }
		switch (clock_mode)
		{
		case 0:	// 시계모드
			showClock();
			break;
		
		case 1:	// 온도모드
			showTnH(temp, 0);
			break;
		
		case 2:	// 습도모드
			showTnH(humi, 1);
			break;
		
		default:
			break;
		}
	}
	// 알람설정기능은 시간표시기능에서만 작동, 알람설정기능이 활성화라면 모드버튼 비활성화 됨.
	// 또한, 시간수정모드가 활성화 된 상태에서 모드전환이 이루어진다면 값은 자동저장 됨.
	// 그리고 시간수정모드는 비활성화 됨.
}

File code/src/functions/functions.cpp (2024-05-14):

#include "functions.h"

/* Function for Displaying Time */
void displayTime(int h, int m)	//시간 출력하는 함수
{
	ledclear();
	updateHour(h);
	updateMin(m);
	strip.show();
}
void updateHour(int h)			//시단위를 표시하는 함수
{
	printled(3);
	//오전 오후 출력
	if(h < 12)	{	printled(29);	printled(30);}
	else		{	printled(29);	printled(28);}
	//시간 출력
	switch(h) {
		case 0:		printled(31);	printled(26);	break;
		case 1:		printled(27);					break;
		case 2:		printled(26);					break;
		case 3:		printled(17);					break;
		case 4:		printled(19);					break;
		case 5:		printled(18);	printled(15);	break;
		case 6:		printled(16);	printled(15);	break;
		case 7:		printled(14);	printled(7);	break;
		case 8:		printled(16);	printled(5);	break;
		case 9:		printled(6);	printled(4);	break;
		case 10:	printled(31);					break;
		case 11:	printled(31);	printled(27);	break;
		case 12:	printled(31);	printled(26);	break;
		case 13:	printled(27);					break;
		case 14:	printled(26);					break;
		case 15:	printled(17);					break;
		case 16:	printled(19);					break;
		case 17:	printled(18);	printled(15);	break;
		case 18:	printled(16);	printled(15);	break;
		case 19:	printled(14);	printled(7);	break;
		case 20:	printled(16);	printled(5);	break;
		case 21:	printled(6);	printled(4);	break;
		case 22:	printled(31);					break;
		case 23:	printled(31);	printled(27);	break;
	}
}
void updateMin(int m)			//분단위를 표시하는 함수
{
	if(m) printled(2);
	int ten = m/10;
	switch (ten) {
		case 1:	printled(23); printled(2); break;
		case 2:	printled(23); printled(32); break;
		case 3:	printled(23); printled(33); break;
		case 4:	printled(23); printled(25); break;
		case 5:	printled(23); printled(24); break;
	}
	m-=ten*10;
	switch (m) {
		case 1:	printled(20);	break;
		case 2:	printled(21);	break;
		case 3:	printled(8);	break;
		case 4:	printled(11);	break;
		case 5: printled(22);	break;
		case 6:	printled(9);	break;
		case 7:	printled(12);	break;
		case 8:	printled(10);	break;
		case 9:	printled(13);	break;
	}
}

/* Function for Sensing Switch */
int sensingSW(int index)		//스위치 센싱 함수
{
	bool reading = digitalRead(swpin[index]);
	if (reading != l_sw_stat[index]) 
		l_deb_tme[index] = time;	// 스위치 값을 처음 읽고는, 바운싱인지 아닌지 확인하는 코드
	if ((time - l_deb_tme[index]) < DEB_DLY) {		// 스위치가 바운싱되었을때는 아무것도 안 함
    	l_sw_stat[index] = reading;
		return NONE; 
	}
	if (reading == sw_org_stat[index]) {			// 스위치를 읽은 값이 스위치 상태와 같다면
    	l_sw_stat[index] = reading;
		return NONE;
	}
	sw_org_stat[index] = reading;
	//아래 코드는 디바운싱된 스위치의 상태애서, 스위치의 상태가 변경되었을 때 작동하는 코드이다. 
	if (sw_org_stat[index] == LOW) {				// 스위치가 눌렸다면
		// Serial.println("switch_pressed");
		sw_w[index] = time;
    	l_sw_stat[index] = reading;
		if(sw_w[index] < time-SW_INTERVAL) {
			// Serial.println("Switch is released by system.");
	    	l_sw_stat[index] = reading;
			return LONG;
		} else { return NONE; }
	} else {										// 스위치가 때졌다면
		// Serial.println("switch_released");
    	l_sw_stat[index] = reading;
		return (sw_w[index] < time-SW_INTERVAL) ?  LONG : SHORT;
	}
}

/* Function for controlling LED */
void changeLEDbright()			//LED밝기 제어하는 함수
{
	bright = (bright >= MAX_BRI) ? INCREASE_BRI : bright+INCREASE_BRI;
	strip.setBrightness(bright);
	// Serial.print("Changed brightness: ");
	// Serial.println(bright);
	if(isChangeMode) {
		showTnH(clock_mode, celsius, humidity);
		isChangeMode = false;
	}
	else
		displayTime(hour, min);
}
void changeLEDcolor()			//LED색깔 제어하는 함수
{
	//Serial.println("change color");
	ledmode++;
	if (ledmode > COLOR_CNT) ledmode = 0;
	if(ledmode) {
		r = color[ledmode][0];
		g = color[ledmode][1];
		b = color[ledmode][2];
		w = color[ledmode][3];
	}
	displayTime(hour, min);
}
void printled(int n)			//LED에 색상 할당하는 함수
{
	if (ledmode == 0) {
		rSeed++;
		randomSeed(rSeed);
		byte rand = random(1, COLOR_CNT);
		r = color[rand][0];
		g = color[rand][1];
		b = color[rand][2];
		w = color[rand][3];
	}
	strip.setPixelColor(n, r, g, b, w);
}
void ledclear()					//LED색상 초기화하는 함수
{
	for (int i = 0; i < strip.numPixels(); i++)
		strip.setPixelColor(i, 0, 0, 0, 0);
	strip.show();
}
void startMotion() {			// 시계가 처음 시작될 때 대각선으로 불 켜지는 함수
	strip.setBrightness(255);
	int gb[12] = {0, -50, -100, -150, -200, -250, -300, -350, -400, -450, -500, 0};	//해당하는 그룹의 밝기
	int delta[12] = {5, 5, 5, 5, 5, 5, 5, 5, 5, 5, 5, 2};
	ledclear();
	for(int i = 0; i < 240; i++) {
		for(int j = 0; j < 11; j++) {
			if(gb[j]>=0) {	//밝기 값이 유효할 때만
				//해당 그룹의 W.W.LED에 밝기값을 할당한다. 
				switch(j) {
				case 0:
					strip.setPixelColor(0, 0, 0, 0, gb[j]);
					break;
				case 1:
					strip.setPixelColor(1, 0, 0, 0, gb[j]);
					strip.setPixelColor(10, 0, 0, 0, gb[j]);
					break;
				case 2:
					strip.setPixelColor(2, 0, 0, 0, gb[j]);
					strip.setPixelColor(9, 0, 0, 0, gb[j]);
					strip.setPixelColor(11, 0, 0, 0, gb[j]);
					break;
				case 3:
					strip.setPixelColor(3, 0, 0, 0, gb[j]);
					strip.setPixelColor(8, 0, 0, 0, gb[j]);
					strip.setPixelColor(12, 0, 0, 0, gb[j]);
					strip.setPixelColor(22, 0, 0, 0, gb[j]);
					break;
				case 4:
					strip.setPixelColor(4, 0, 0, 0, gb[j]);
					strip.setPixelColor(7, 0, 0, 0, gb[j]);
					strip.setPixelColor(13, 0, 0, 0, gb[j]);
					strip.setPixelColor(21, 0, 0, 0, gb[j]);
					strip.setPixelColor(23, 0, 0, 0, gb[j]);
					break;
				case 5:
					strip.setPixelColor(6, 0, 0, 0, gb[j]);
					strip.setPixelColor(14, 0, 0, 0, gb[j]);
					strip.setPixelColor(20, 0, 0, 0, gb[j]);
					strip.setPixelColor(24, 0, 0, 0, gb[j]);
					strip.setPixelColor(34, 0, 0, 0, gb[j]);
					break;
				case 6:
					strip.setPixelColor(5, 0, 0, 0, gb[j]);
					strip.setPixelColor(15, 0, 0, 0, gb[j]);
					strip.setPixelColor(19, 0, 0, 0, gb[j]);
					strip.setPixelColor(25, 0, 0, 0, gb[j]);
					strip.setPixelColor(33, 0, 0, 0, gb[j]);
					break;
				case 7:
					strip.setPixelColor(16, 0, 0, 0, gb[j]);
					strip.setPixelColor(18, 0, 0, 0, gb[j]);
					strip.setPixelColor(26, 0, 0, 0, gb[j]);
					strip.setPixelColor(32, 0, 0, 0, gb[j]);
					break;
				case 8:
					strip.setPixelColor(17, 0, 0, 0, gb[j]);
					strip.setPixelColor(27, 0, 0, 0, gb[j]);
					strip.setPixelColor(31, 0, 0, 0, gb[j]);
					break;
				case 9:
					strip.setPixelColor(28, 0, 0, 0, gb[j]);
					strip.setPixelColor(30, 0, 0, 0, gb[j]);
					break;
				case 10:
					strip.setPixelColor(29, 0, 0, 0, gb[j]);
					break;
				}
			}
		}
		strip.show();
		for(int j = 0; j < 11; j++) {	//밝기값 재설정
			if(gb[j] == 250) {
				delta[j] = -5;
			}
			gb[j] += delta[j];
		}
		analogWrite(FLICKER_PIN, gb[11]);
		if(gb[11] == 250) delta[11] = -2;
		gb[11] += delta[11];
		delay(10);
	}
	strip.setBrightness(MAX_BRI);
}
void blink() {
	if(sec%2) {
		if(isClockChange || isAlarmChange) {
			strip.setPixelColor(2, 0, 0, 0, MAX_BRI);
			strip.setPixelColor(3, 0, 0, 0, MAX_BRI);
			strip.show();
		}
		digitalWrite(FLICKER_PIN, HIGH);
	} else {
		if(isClockChange || isAlarmChange) {
			strip.setPixelColor(2, 0, 0, 0, 0);
			strip.setPixelColor(3, 0, 0, 0, 0);
			strip.show();
		}
		digitalWrite(FLICKER_PIN, LOW);
	}
}
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

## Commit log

2021-06-23 basic setting 코드의 주석을 수정하고 작업을 할 수 있게 준비하였다.
    [han_clock_v2.ino]
2021-07-28 create PCB file
    [hanClock.kicad_pcb, hanClock.sch]
2021-08-26 Finished design 커밋을 안 한 한참동안 PCB 다 만들고 외부 디자인도 다 해서 파일을 이렇게 저장했다.
    [case.stl, diffuser.stl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]
2021-08-31 어지러운 코드를 정리하였다. 도저히 영어로는 뭐라 할지 모르겠어서 한국어로 커밋했다. 제목 그대로 v1에서 배껴와서 각종 환경설정 빛 맞지 않는 변수명들을 모두 수정하고, 더러운 코드들을 모두 보기 좋게 정렬하였다.
    [case.stl, letter_panel.dxf]
2021-09-02 코드는 수정 중 수정 중에 커밋을 한다. 이번 작업에는 상수 추가, 모든 기능에 대한 설명 추가, DHT모듈 임포트 등의 수정사항이 있습니다.
    [functions.cpp, functions.h, han_clock_v2.ino]
2021-09-08 함수 뜯어고치기 버튼 관련 변수명 정리 및 구조 개선, 함수 수정 중 무언가를 하는 중에 하는 커밋은 좋지 않다 하지만... 잃단 해 본다.
    [functions.cpp, functions.h, han_clock_v2.ino]
2021-09-09 아직도 코드는 수정 중 현재, 변수명을 드디어 정리했고, v1의 유산인 많은 더러운 코딩 실력도 최대한 정리했다. 그러나 버튼 함수의 if문 깊이는 도저히...ㅜ 여튼, 열심히 수정 중이다.
    [functions.cpp, functions.h, han_clock_v2.ino]
2021-09-11 PCB디자인 하는 중
    [hanClock.kicad_pcb, hanClock.sch]
2021-09-15 Revise PCB design
    [hanClock-B_Cu.gbr, hanClock-B_Mask.gbr, hanClock-B_Paste.gbr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]
2021-10-18 코드작성중
2021-11-15 LED출력코드 수정완료 LED출력하는 주소값들을 모두 수정 완료하였다
    [hanClock.kicad_pcb]
2021-11-23 리드미 수정 및 향후 계획 수립
2021-12-09 의사코드 작성 오늘은 의사코드를 아침에 작성해 보았다. 아직 버튼 동작 구현 부분에서 조금은 덜 작성한 부분이 있다. 특히, 알람버튼 코드는 어렵...
2022-01-06 new commit at win11 테스트용 커밋
2022-01-06 과거를 청산하는 프로그램 수정 많은 것을 했다. 전체 코드에 대한 통일성 및 부족한 함수 추가, 코드 정리 완료. 또한, 변수명 재설정 및 상수 재정의 완료, 헤더파일 정리. 버튼 함수 피의 숙청함
    [functions.cpp, functions.h, han_clock_v2.ino]
2022-01-06 Changed a little parts 우선, 아까전 커밋 때보다 시계구동코드를 좀 적어두었다. 또한, 거의 모든 숫자를 상수화 시켜서 상수에조차 주석을 달았다. 나는야 주석왕... 이제 자야지...zZzZ
2022-01-07 폴더 재구성 및 코드 적는중 우선, 프로젝트의 전체 구성 자체를 재정리했다. 카테고리에 맞게 모든 파일들을 폴더로 넣었다. 또한, 코드에서 시간수정모드 및 알람수정모드의 경우에 대한 코딩을 완료하였다. 다만, 알람모드 기능에 대한 정의가 불확실하여 코드를 짜지 못한 부분도 있다.
    [functions.cpp, functions.h, han_clock_v2.ino]
2022-01-08 Finished SW motion code 스위치에 반응하는 모든 코드 작성 완료
2022-02-12 Resync files 컴퓨터 갈아엎으면서 바뀐 파일 등 기타 모든 파일들 일괄 커밋
    [hanClock.kicad_pcb, hanClock.kicad_sch]
2024-05-03 Sync files 이 커밋은 별다른 건 없고, 두 환경-노트북과 데스크톱-간에 서로 호환이 되는지 확인하는 커밋이다.
2024-05-03 Clean every files
    [case.stl, diffuser.stl, letter_panel.dxf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]
2024-05-05 코드 수정중
2024-05-05 중간에 커밋
2024-05-14 코드 수정중 거의 다 수정해 가는 중이다. 지금은, 코드가 뒤죽박죽이라, 코드를 재정비해야한다.
    [code.ino, functions.cpp, functions.h]
